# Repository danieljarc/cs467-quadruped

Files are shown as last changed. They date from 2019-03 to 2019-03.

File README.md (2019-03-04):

# CS467-400 Quadruped Project

Our team created a 3D-printed, quadruped robot using C++ and an Arduino Uno. The quadruped has 3 degrees of freedom on each leg and is capable of walking, turning in place,  body rotation, and body translation. The user interface was created using Qt and sends commands to the quadruped via bluetooth.

## Software
- Qt
- Arduino IDE

## Hardware
- Arduino Uno
- Adafruit 16 PWM servo shield
- HC-05 or HC-06 bluetooth module
- 9V battery with barrel plug adapter
- 7.4V Lipo battery with 5V UBEC 
- 12 SG90 or equivalent servos
- 3D printer
- M2, M3 screws, ball bearings, wire, resistors

## Deployment
1. Print part files, assemble and wire
2. Upload movement sketch to Uno
3. Load and compile Qt project file

## Usage
Connect to the quadruped via the connect button. Translate the body while the legs remain planted using the translate mode. Pitch, roll and yaw the body while the legs remain planted using the rotate mode. Walk and turn using the walk mode. The sit, stand and center commands are available in all modes. 

## Authors
- Michael/Yau Chan
- Daniel Jarc
- Jacob Powers

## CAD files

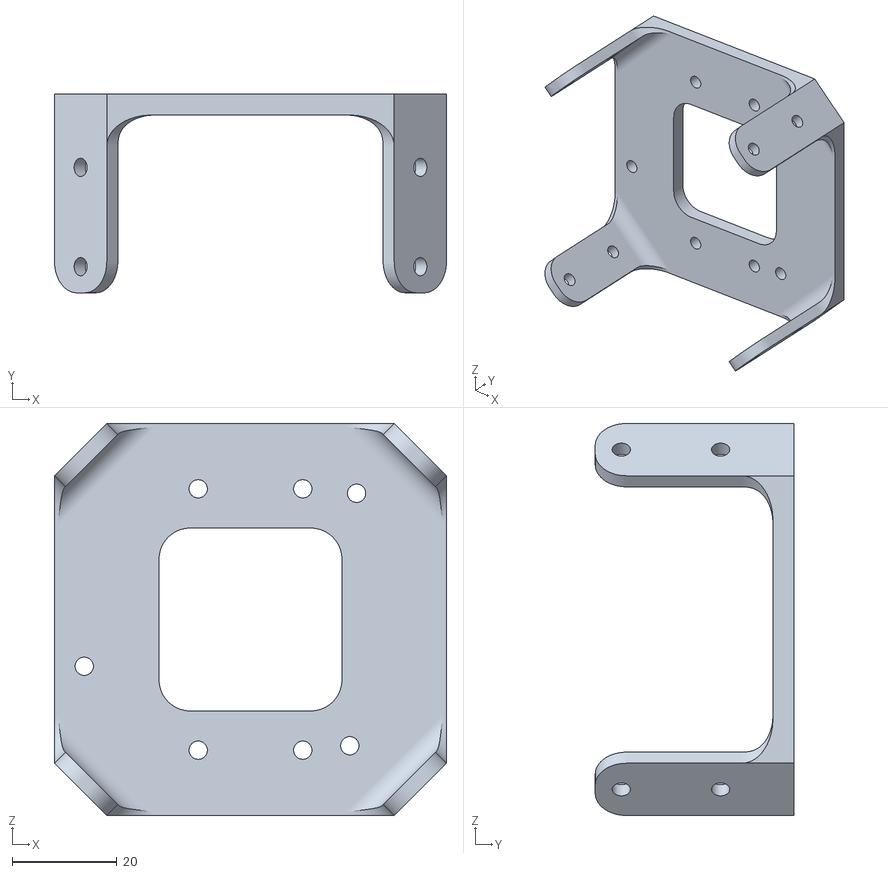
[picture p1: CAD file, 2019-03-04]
parts/v5_center.stl
75.0 x 38.0 x 75.0

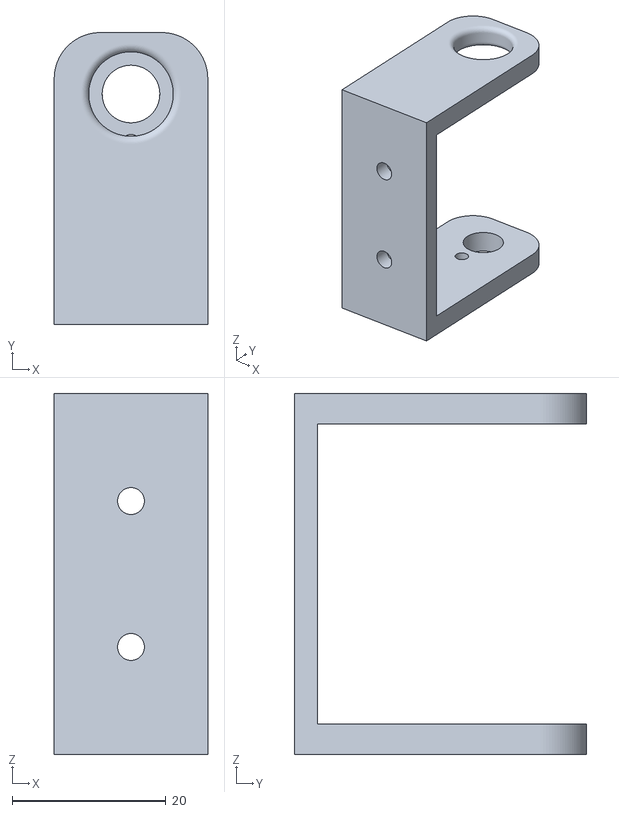
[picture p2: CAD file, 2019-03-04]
parts/v5_shoulder_bracket.stl
20.0 x 38.0 x 47.0

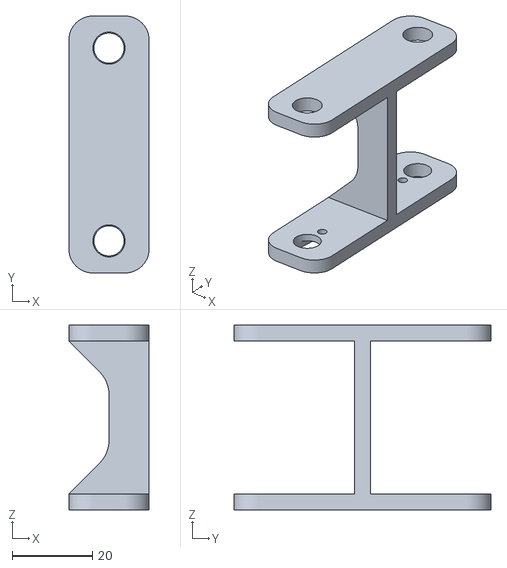
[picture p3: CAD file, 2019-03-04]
parts/v5_femur.stl
20.0 x 64.0 x 46.0

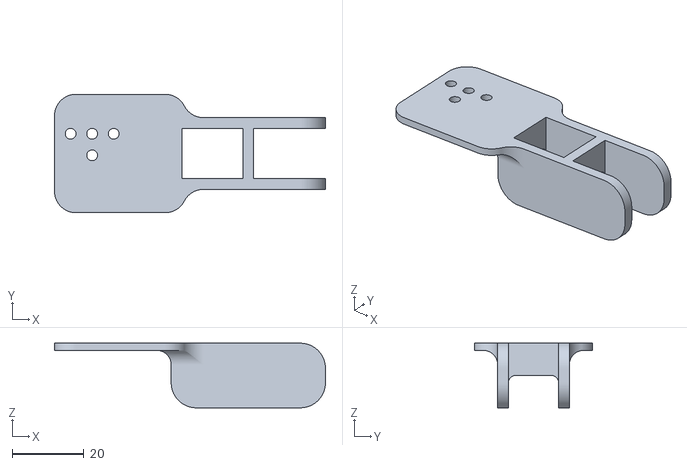
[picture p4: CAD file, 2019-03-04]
parts/v5_tibia_B.stl
75.5 x 33.0 x 18.0

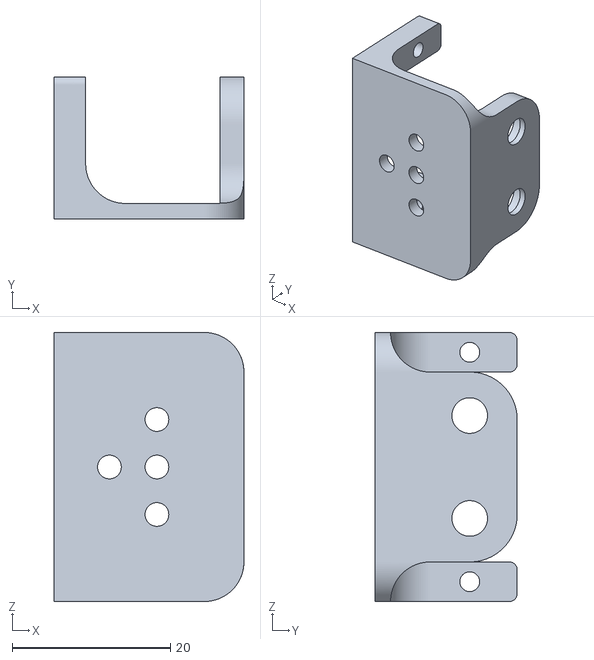
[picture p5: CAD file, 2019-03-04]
parts/v5_servo_bracket.stl
24.0 x 18.0 x 34.0

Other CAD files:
parts/v5_tibia_A.stl
parts/v5_center.ipt
parts/v5_femur.ipt
parts/v5_servo_bracket.ipt
parts/v5_shoulder_bracket.ipt
parts/v5_tibia_A.ipt
parts/v5_tibia_B.ipt

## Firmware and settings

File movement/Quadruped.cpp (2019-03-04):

/*********************************************************************
* CS467 - Quadruped Movement and Input Processing
* Author: Daniel Jarc (jarcd)
* Date: March 18, 2019
* Description: Processes user input, calculates servo angles
* using IK, executes commands. 
*********************************************************************/

#include "Quadruped.h"
#include "SoftwareSerial.h"

Quadruped::Quadruped(SoftwareSerial * bt_module) {

  //Bluetooth initialization
  bt = bt_module;
  bt->begin(9600);
  bt->println("HC-06 started"); 
}

/*********************************************************************
* initialize()
* Description: Sets default pin mappings, pwm min and max values,
* servo min and max angle values.
*********************************************************************/
void Quadruped::initialize(){

  //Used for printing quadruped info while connected
  Serial.begin(9600);

  //Servo shield initialization
  pwm.begin();
  pwm.setPWMFreq(60);
  
  //Servo pin mapping 
  servoPin[LEG_1][COXA]=12;
  servoPin[LEG_1][FEMUR]=13;
  servoPin[LEG_1][TIBIA]=14;
  servoPin[LEG_2][COXA]=3;
  servoPin[LEG_2][FEMUR]=4;
  servoPin[LEG_2][TIBIA]=5;
  servoPin[LEG_3][COXA]=6;
  servoPin[LEG_3][FEMUR]=7;
  servoPin[LEG_3][TIBIA]=8;
  servoPin[LEG_4][COXA]=9;
  servoPin[LEG_4][FEMUR]=10;
  servoPin[LEG_4][TIBIA]=11;

  //Servo PWM min/max values
  pwmMin[LEG_1][COXA]=275;
  pwmMax[LEG_1][COXA]=520;  
  pwmMin[LEG_1][FEMUR]=275;
  pwmMax[LEG_1][FEMUR]=475;
  pwmMin[LEG_1][TIBIA]=215;
  pwmMax[LEG_1][TIBIA]=500; 
  pwmMin[LEG_2][COXA]=200;
  pwmMax[LEG_2][COXA]=450;
  pwmMin[LEG_2][FEMUR]=180;
  pwmMax[LEG_2][FEMUR]=450;
  pwmMin[LEG_2][TIBIA]=180;
  pwmMax[LEG_2][TIBIA]=430;  
  pwmMin[LEG_3][COXA]=230;
  pwmMax[LEG_3][COXA]=470;
  pwmMin[LEG_3][FEMUR]=200;
  pwmMax[LEG_3][FEMUR]=430;
  pwmMin[LEG_3][TIBIA]=250;
  pwmMax[LEG_3][TIBIA]=500;
  pwmMin[LEG_4][COXA]=210;
  pwmMax[LEG_4][COXA]=440;
  pwmMin[LEG_4][FEMUR]=250;
  pwmMax[LEG_4][FEMUR]=490;
  pwmMin[LEG_4][TIBIA]=170;
  pwmMax[LEG_4][TIBIA]=410;
  
  //Servo degree-pwm mapping
  servoDegMin[LEG_1][COXA]=0;
  servoDegMax[LEG_1][COXA]=90;
  servoDegMin[LEG_1][FEMUR]=135;
  servoDegMax[LEG_1][FEMUR]=45;
  servoDegMin[LEG_1][TIBIA]=120;
  servoDegMax[LEG_1][TIBIA]=0;  
  servoDegMin[LEG_2][COXA]=-90;
  servoDegMax[LEG_2][COXA]=0;
  servoDegMin[LEG_2][FEMUR]=45;
  servoDegMax[LEG_2][FEMUR]=135;
  servoDegMin[LEG_2][TIBIA]=0;
  servoDegMax[LEG_2][TIBIA]=120; 
  servoDegMin[LEG_3][COXA]=-180;
  servoDegMax[LEG_3][COXA]=-90;
  servoDegMin[LEG_3][FEMUR]=135;
  servoDegMax[LEG_3][FEMUR]=45;
  servoDegMin[LEG_3][TIBIA]=120;
  servoDegMax[LEG_3][TIBIA]=0;  
  servoDegMin[LEG_4][COXA]=90;
  servoDegMax[LEG_4][COXA]=180;
  servoDegMin[LEG_4][FEMUR]=45;
  servoDegMax[LEG_4][FEMUR]=135;
  servoDegMin[LEG_4][TIBIA]=0;
  servoDegMax[LEG_4][TIBIA]=120;

  //Center body
  center();
  moveServos();
  yield(); 
}

/*********************************************************************
* processCommands()
* Description: Reads a byte from serial then executes the appropriate
* command. 
*********************************************************************/
void Quadruped::processCommands(){

  if (bt->available() > 0) {
    char c = bt->read();
    switch(c){
      case '`':                       //Print quadruped info
        printQuadInfo();
        break;
      case ',':                       //Sit
        sit();
        break;
      case '.':                       //Stand
        stand();
        break;
      case '/':                       //Center body
        center();
        moveServos();
        break;
      case 'q':                       //Translate body upward
        translateBody(0.0,0.0,1.0);
        break;
      case 'e':                       //Translate body downward
        translateBody(0.0,0.0,-1.0);
        break;
      case 'w':                       //Translate body forward
        translateBody(1.0,0.0,0.0);
        break;
      case 's':                       //Translate body back
        translateBody(-1.0,0.0,0.0);
        break; 
      case 'a':                       //Translate body left
        translateBody(0.0,-1.0,0.0);
        break;
      case 'd':                       //Translate body right
        translateBody(0.0,1.0,0.0);
        break;
      case 'u':                       //Yaw body left
        rotateBody(0.0,0.0,-10.0);
        break;
      case 'o':                       //Yaw body right
        rotateBody(0.0,0.0,10.0);
        break;
      case 'i':                       //Pitch body down
        rotateBody(0.0,-10.0,0.0);
        break; 
      case 'k':                       //Pitch body up
        rotateBody(0.0,10.0,0.0);
        break;
      case 'j':                       //Roll body left
        rotateBody(-10.0,0.0,0.0);
        break;
      case 'l':                       //Roll body right
        rotateBody(10.0,0.0,0.0);
        break;
      case 't':                       //Walk forward
        walk(FORWARD);
        break;
      case 'f':                       //Walk left
        walk(LEFT);
        break;   
      case 'h':                       //Walk right
        walk(RIGHT);
        break;
      case 'g':                       //Walk back
        walk(BACK);
        break;
      case 'r':                       //Turn left
        turn(LEFT);
        break;
      case 'y':                       //Turn right
        turn(RIGHT);
        break;
      default:
        break;
    }
  }
}

/*********************************************************************
* printQuadInfo()
* Description: Prints current quadruped body and leg data.
*********************************************************************/
void Quadruped::printQuadInfo(){  
  Serial.println("---------");
  Serial.println("Body Info");
  Serial.println("---------");
  Serial.print("X: ");
  Serial.print(bodyPos[X]); 
  Serial.print(", Y: ");
  Serial.print(bodyPos[Y]);
  Serial.print(", Z: ");
  Serial.print(bodyPos[Z]); 
  Serial.print(", Roll(u): ");
  Serial.print(bodyAngle[ROLL]);
  Serial.print(", Pitch(v): ");
  Serial.print(bodyAngle[PITCH]); 
  Serial.print(", Yaw(w): ");
  Serial.println(bodyAngle[YAW]);
  Serial.println("--------");
  Serial.println("Leg Info");
  Serial.println("--------");
  for (int i = 0; i < LEGS; i++){
    Serial.print("Leg ");
    Serial.print(i);
    Serial.print(" - ");
    Serial.print("X: ");
    Serial.print(legPos[i][X]); 
    Serial.print(", Y: ");
    Serial.print(legPos[i][Y]);
    Serial.print(", Z: ");
    Serial.print(legPos[i][Z]); 
    Serial.print(", Coxa Angle: ");
    Serial.print(legAngle[i][COXA]);
    Serial.print(", Femur Angle: ");
    Serial.print(legAngle[i][FEMUR]);  
    Serial.print(", Tibia Angle: ");
    Serial.println(legAngle[i][TIBIA]);  
  }
}
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

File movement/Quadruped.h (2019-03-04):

/*********************************************************************
* CS467 - Quadruped Movement and Input Processing
* Author: Daniel Jarc (jarcd)
* Date: March 1, 2019
* Description: Processes user input to serial, calculates servo angles
* using IK, executes commands. 
*********************************************************************/

#ifndef QUADRUPED_H
#define QUADRUPED_H

#include <Arduino.h>
#include <Wire.h>
#include <Adafruit_PWMServoDriver.h>
#include "SoftwareSerial.h"

//Definitions
#define FORWARD 0
#define BACK 1
#define LEFT 2
#define RIGHT 3
#define X 0            
#define Y 1             
#define Z 2             
#define ROLL 0
#define PITCH 1
#define YAW 2
#define LEG_1 0
#define LEG_2 1
#define LEG_3 2
#define LEG_4 3
#define COXA 0
#define FEMUR 1
#define TIBIA 2
#define COXA_LENGTH 2.5f 
#define FEMUR_LENGTH 4.3f
#define TIBIA_LENGTH 7.1f
#define LEGS 4
#define LEG_SERVOS 3

//Solution struct is used to store IK solutions
struct Solution {
  float legAngle[4][3];
  float legPos[4][3];
};

class Quadruped {

  public:
    Quadruped(SoftwareSerial* bt_module);
    void initialize();
    void processCommands();
    void printQuadInfo();
    
  private:
    void translateBody(float dX, float dY, float dZ);
    void rotateBody(float dU, float dV, float dW);
    void walk(int dir);
    void turn(int dir);
    void sit();
    void stand();
    void center();
    void legIK(struct Solution* sol);
    void setLegValues(struct Solution* sol);
    void moveLeg(int leg, float dX, float dY, float dZ);
    void moveServos();

    Adafruit_PWMServoDriver pwm = Adafruit_PWMServoDriver();
    SoftwareSerial* bt;
    float bodyAngle[3];
    float bodyPos[3];
    float legAngle[4][3];
    float legPos[4][3];
    int pwmMin[4][3];
    int pwmMax[4][3];
    int servoPin[4][3];
    int servoDegMin[4][3];
    int servoDegMax[4][3];
};
#endif

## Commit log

2019-01-03 Part files and servo centering code update
    [body_v3.ipt, body_v3.stl, femur_v3.ipt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]
2019-01-21 Updated servo centering code and added project plan.
2019-01-28 IK tests sketch, updated part files
    [body_lower_quarter.ipt, body_lower_quarter.stl, body_upper_quarter.ipt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]
2019-01-28 Single leg IK tests
2019-01-28 Changes to single leg IK tests
2019-02-15 Added Arduino code for bluetooth receive
2019-02-16 Kinematics Research
2019-03-03 Updated GUI source code
    Added comments, removed walk - gait mode 2 state, updated destructor to gracefully disconnect BT, and changed Connect status from state property to action within the connect button slot.
2019-03-04 Updated movement code
    [body_lower_quarter.ipt, body_lower_quarter.stl, body_upper_quarter.ipt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]
2019-03-17 Updated connected() slot for proper connect status reflection.
